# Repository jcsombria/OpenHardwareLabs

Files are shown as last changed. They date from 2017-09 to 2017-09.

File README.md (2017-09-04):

# OpenHardwareLabs
Open source and open hardware virtual and remote laboratories

## Introduction
This repository is a container for open-source/open-hardware remote and virtual labs.

Currently available labs:
- Air Levitation System 

# Air Levitation System

To build the air levitation system:

- Beaglebone Black board setup
  1. Verify you can boot your BBB and you have a working version of Node.js.
  2. Download and install the RIP-server (https://github.com/UNEDLabs/rip-js-server)

- Build the PCB circuit (design files are available in the folder 'AirLevitation/KiCad', and the documentation in 'AirLevitation/doc').

- Build the structure
  1. Print all the structural parts (the .stl files contained in the folder 'AirLevitation/output'). 
  2. Mount the structure and make the connections between the sensors, actuators, circuitry and beaglebone as shown in the schematic.

- EjsS
  1. Download EjsS in your PC or laptop, and open the [lab application](AirLevitation/src/EjsS) in EjsS.  
  2. Press play on EjsS to start the remote lab.

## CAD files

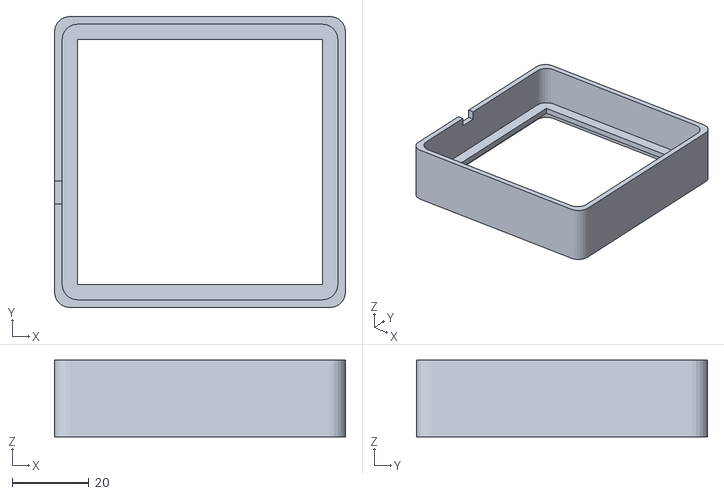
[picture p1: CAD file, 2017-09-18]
AirLevitation/output/fan_cover.stl
76.0 x 76.0 x 20.0

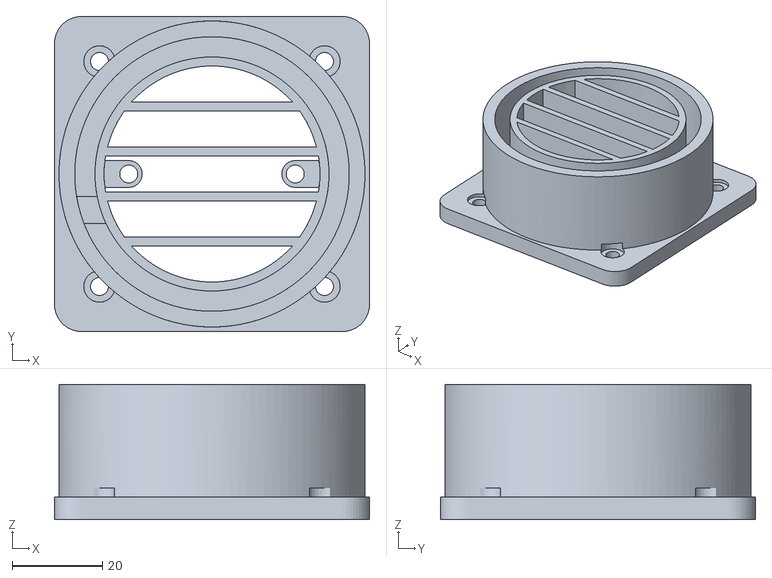
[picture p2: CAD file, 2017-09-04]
AirLevitation/output/tube_support.stl
70.0 x 70.0 x 30.0

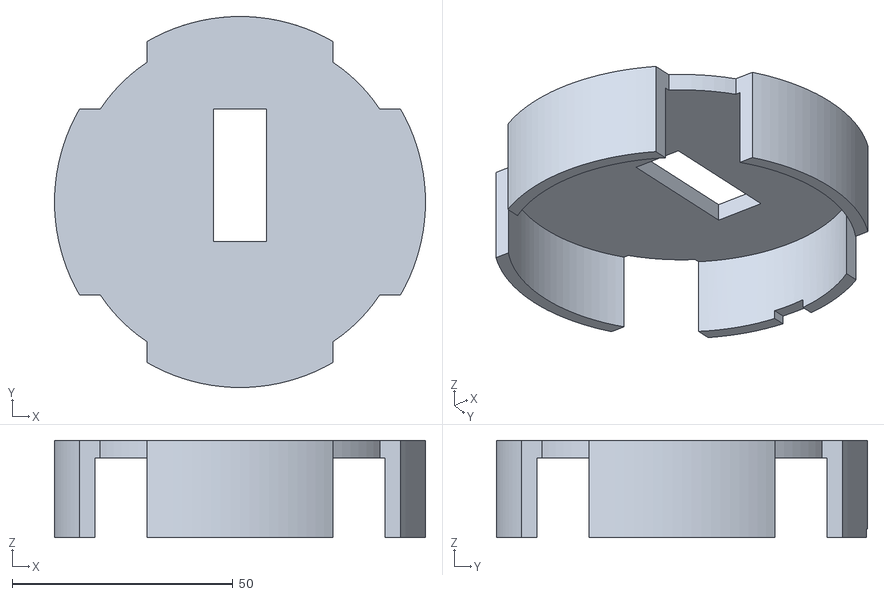
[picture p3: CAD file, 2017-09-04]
AirLevitation/output/base_top.stl
84.0 x 84.0 x 22.0

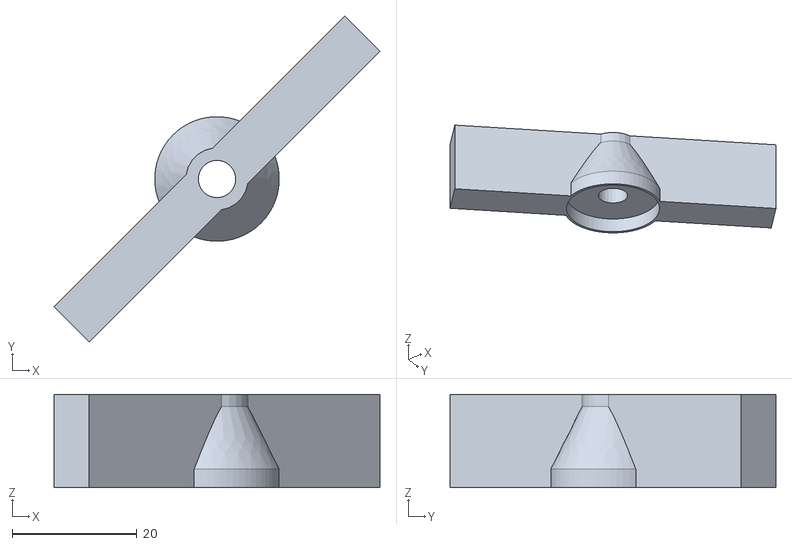
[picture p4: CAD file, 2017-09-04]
AirLevitation/output/blade.stl
52.3 x 52.3 x 15.0

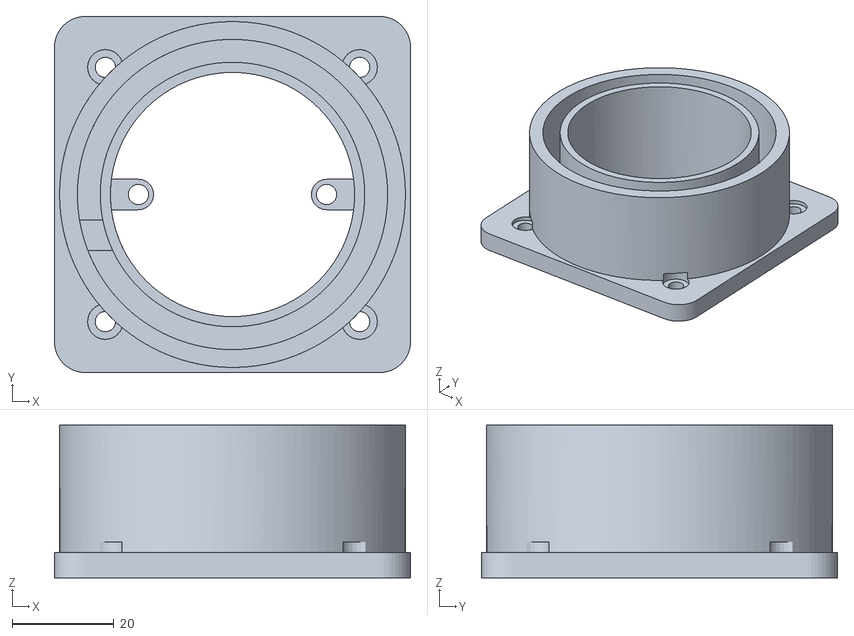
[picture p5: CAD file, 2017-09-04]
AirLevitation/output/tube_support_without_grid.stl
70.0 x 70.0 x 30.0

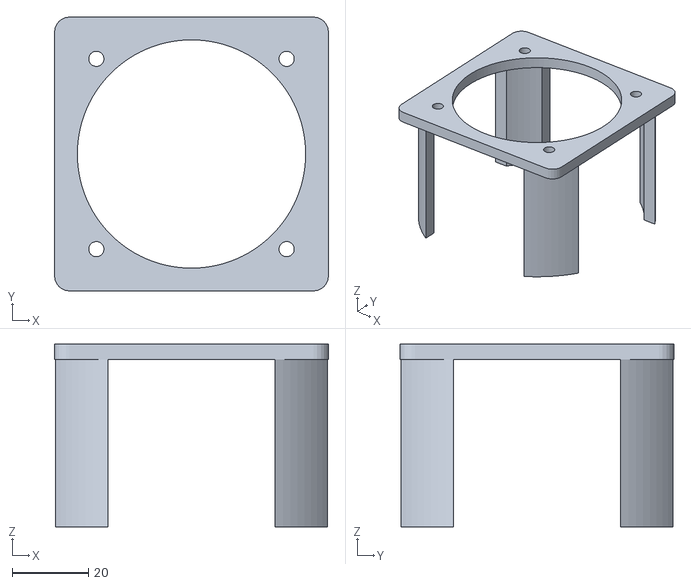
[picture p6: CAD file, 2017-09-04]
AirLevitation/output/fan_support.stl
72.0 x 72.0 x 48.0

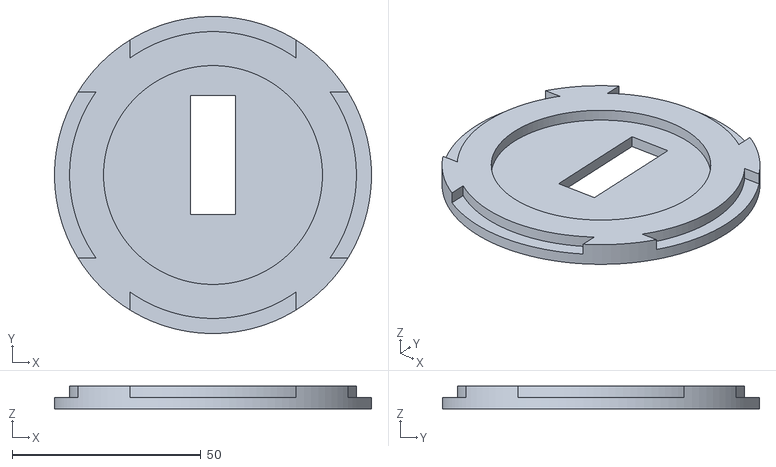
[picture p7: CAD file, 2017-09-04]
AirLevitation/output/base_bottom.stl
84.0 x 84.0 x 6.00

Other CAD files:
AirLevitation/src/parts/AirLevitation.fcstd

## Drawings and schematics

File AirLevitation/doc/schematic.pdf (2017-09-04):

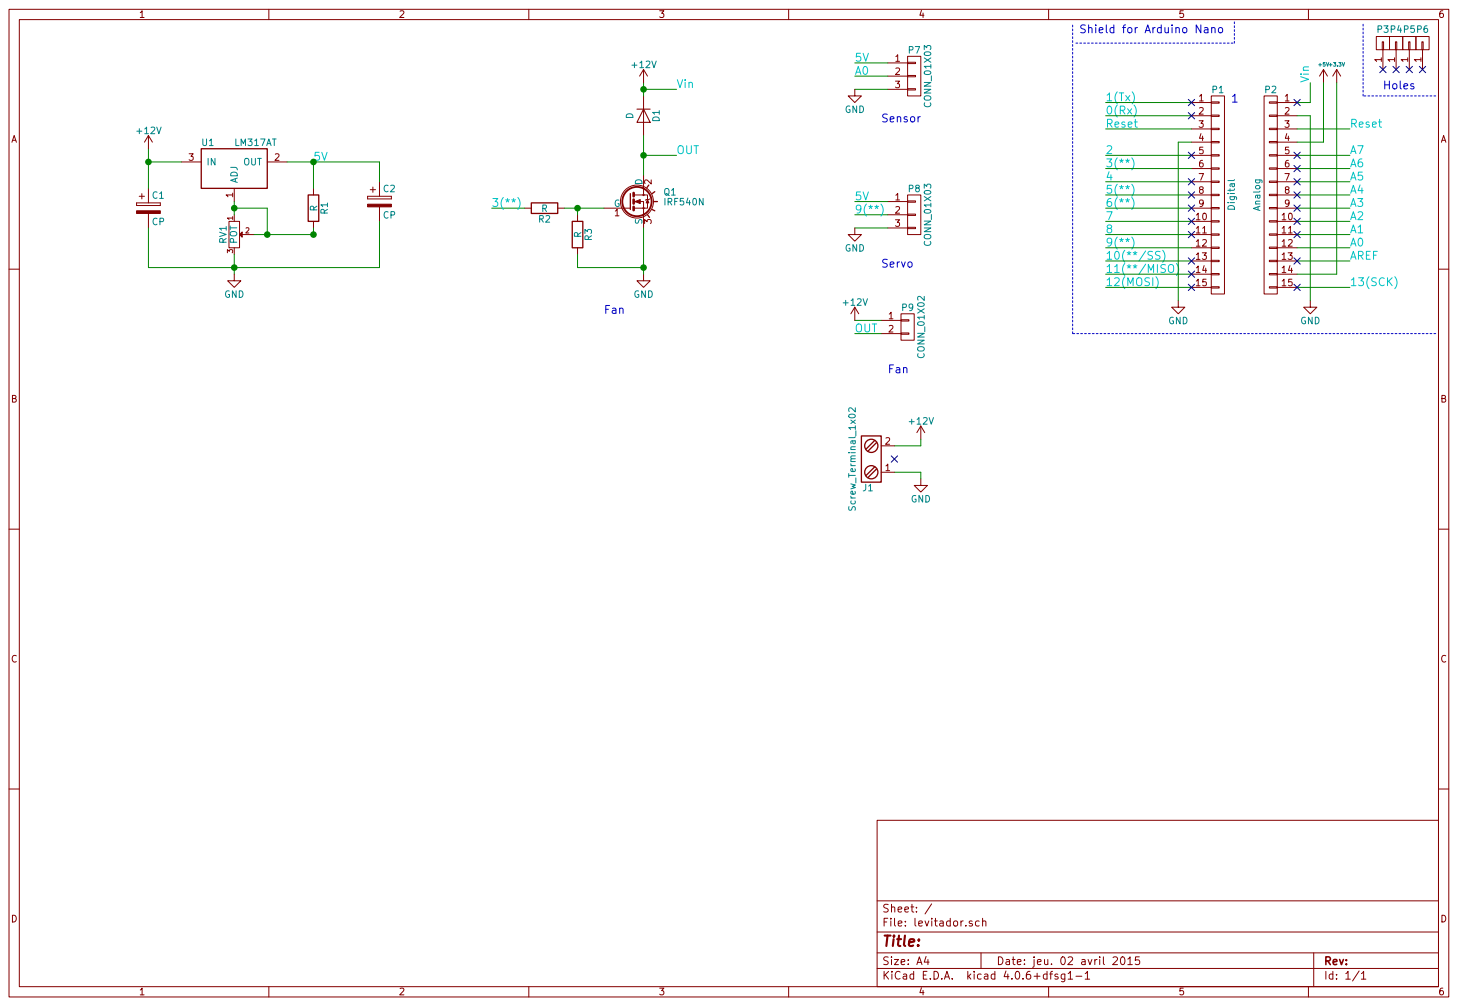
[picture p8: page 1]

Id: 1/1 Title: File: levitador.sch Sheet: /

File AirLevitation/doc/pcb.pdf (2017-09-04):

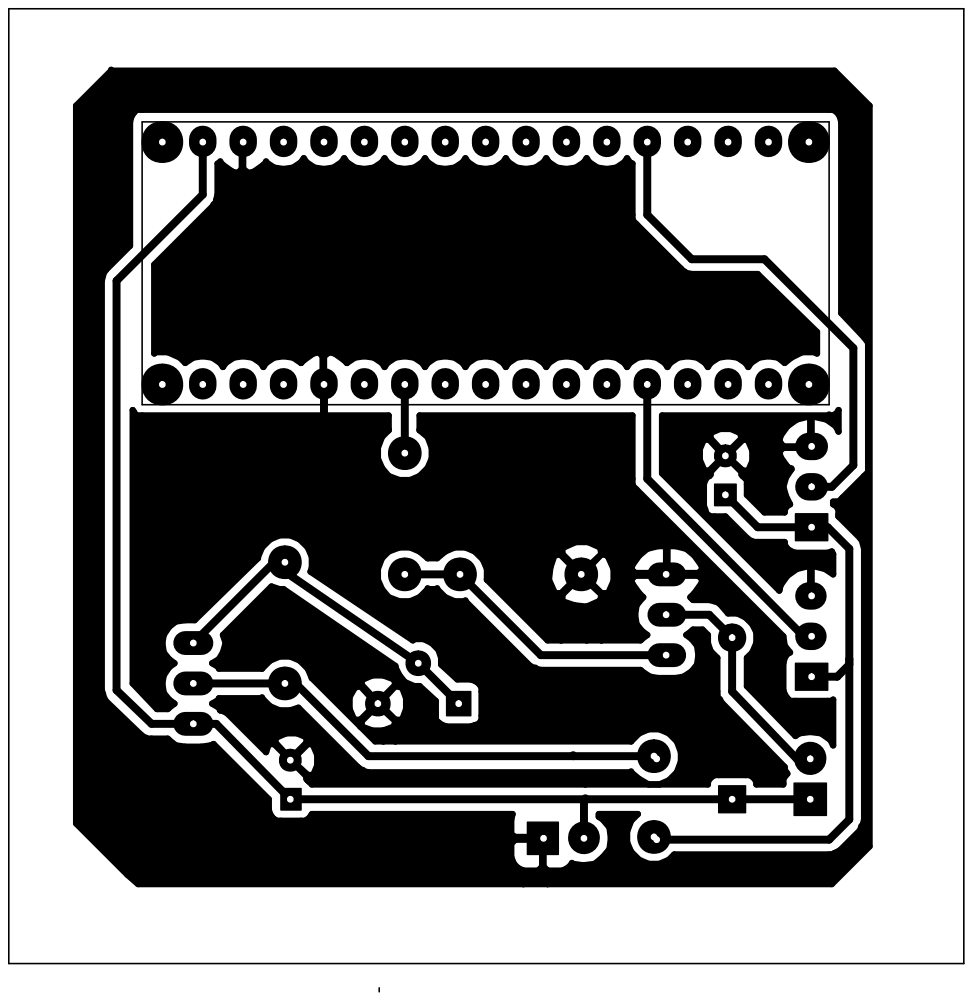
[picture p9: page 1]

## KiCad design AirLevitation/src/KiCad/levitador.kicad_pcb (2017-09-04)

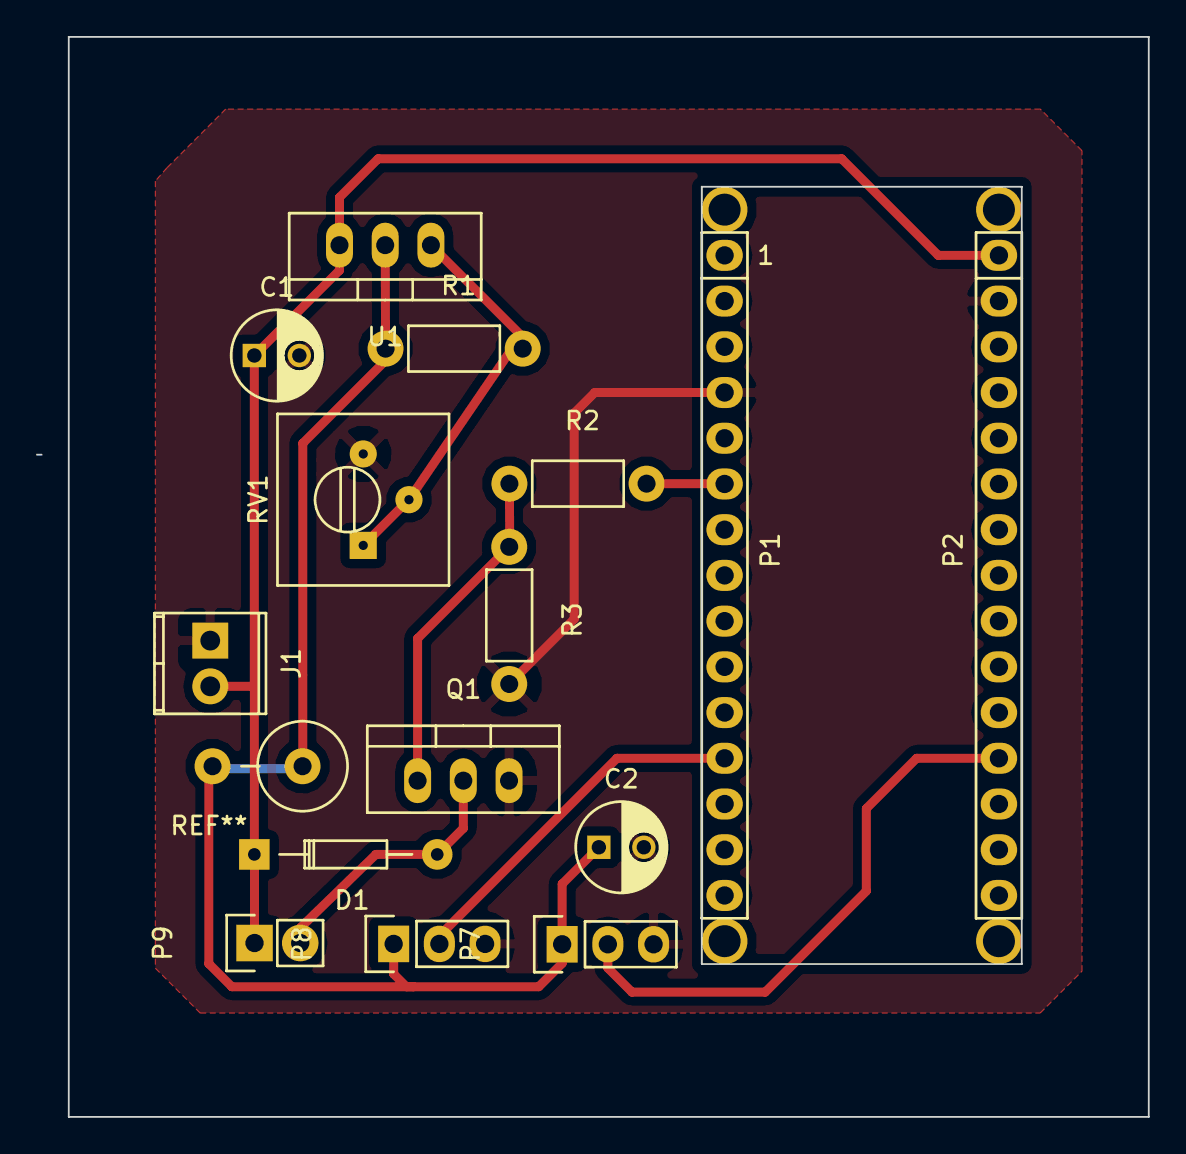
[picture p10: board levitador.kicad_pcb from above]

Board: 2 copper layers, 61.8 x 60.0 mm, 19 parts (0 on the bottom side), 10 nets.

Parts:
C1, C2: CP; C_Radial_D5_L11_P2.5
D1: D; Diode_DO-35_SOD27_Horizontal_RM10
J1: Screw_Terminal_1x02; TerminalBlock_Pheonix_MPT-2.54mm_2pol
P1: Digital; Socket_Strip_Arduino_1x15
P2: Analog; Socket_Strip_Arduino_1x15
P3, P4, P5, P6: CONN_01X01; 1pin_Nano
P7, P8: CONN_01X03; Pin_Header_Straight_1x03
P9: CONN_01X02; Pin_Header_Straight_1x02
Q1: IRF540N; TO-220_Neutral123_Vertical
R1, R2, R3: R; Resistor_Horizontal_RM7mm
RV1: POT; Potentiometer_Trimmer-Suntan-TSR-3386P
U1: LM317AT; TO-220_Neutral123_Vertical

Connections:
+12V: C1.1, D1.1, J1.2, P2.1, P9.1, U1.3
/3(**): P1.6, R2.2
/5V: C2.1, P7.1, P8.1, R1.1, U1.2
/9(**): P1.12, P8.2
/A0: P2.12, P7.2
/OUT: D1.2, P9.2, Q1.2
/Reset: P1.3, P2.3
GND: C1.2, C2.2, J1.1, P1.4, P2.2, P7.3, P8.3, Q1.3, R3.2, RV1.3
unnamed: Q1.1, R2.1, R3.1
unnamed: R1.2, RV1.1, RV1.2, U1.1

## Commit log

2017-09-04 + Added Virtual and Remote EjsS application + Added Structural parts
    [AirLevitation.fcstd, base_bottom.stl, base_top.stl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]
2017-09-04 Added schematic and PCB
    [AirLevitation.sch, levitador.kicad_pcb]
2017-09-18 Added fan cover
    [AirLevitation.fcstd, fan_cover.stl]
